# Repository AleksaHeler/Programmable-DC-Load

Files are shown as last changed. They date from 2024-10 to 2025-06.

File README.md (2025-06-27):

# Programmable DC Load

Flexible programmable DC constant current/power load using Arduin Nano and a custom PCB.

Following some ideas from [this YouTube playlist](https://www.youtube.com/playlist?list=PLUMG8JNssPPzbr4LydbTcBrhoPlemu5Dt) from [Scullcom Hobby Electronics](https://www.youtube.com/@scullcomhobbyelectronics1702).

## PCB design and schematic

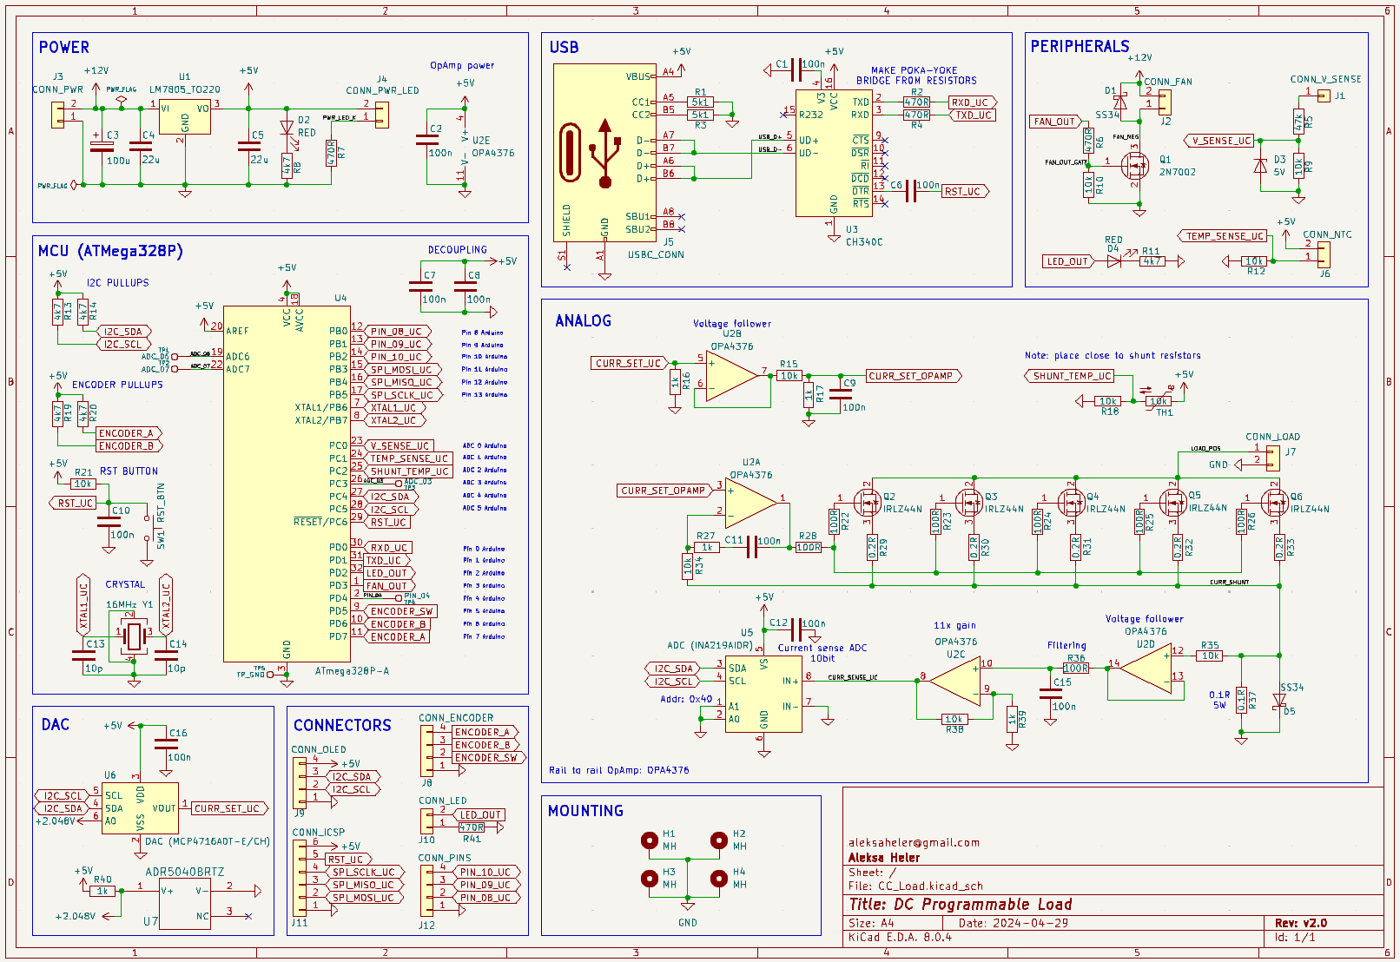
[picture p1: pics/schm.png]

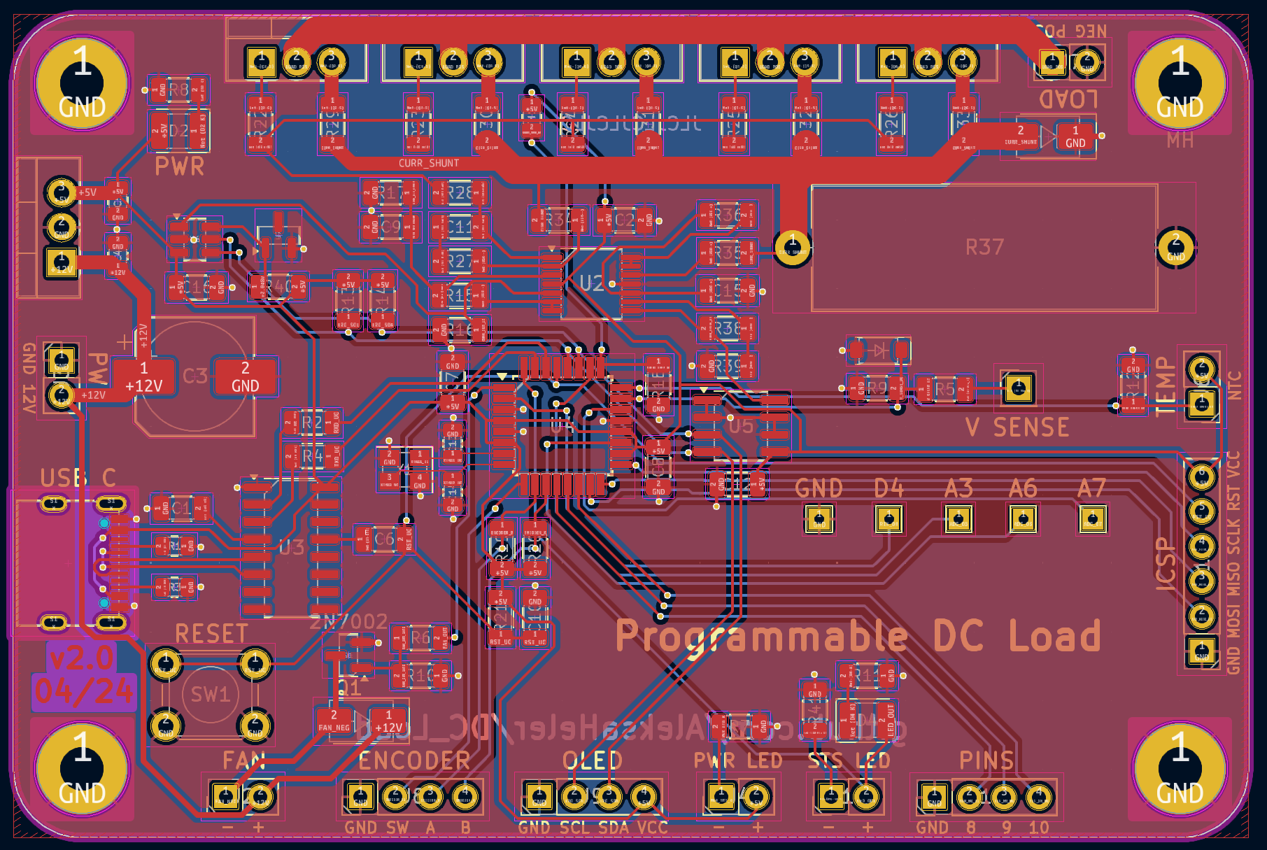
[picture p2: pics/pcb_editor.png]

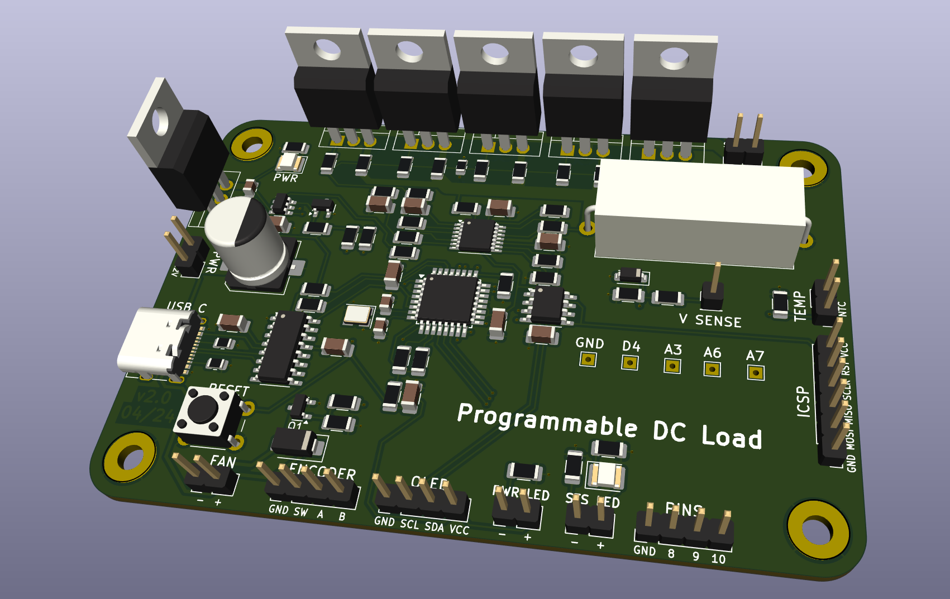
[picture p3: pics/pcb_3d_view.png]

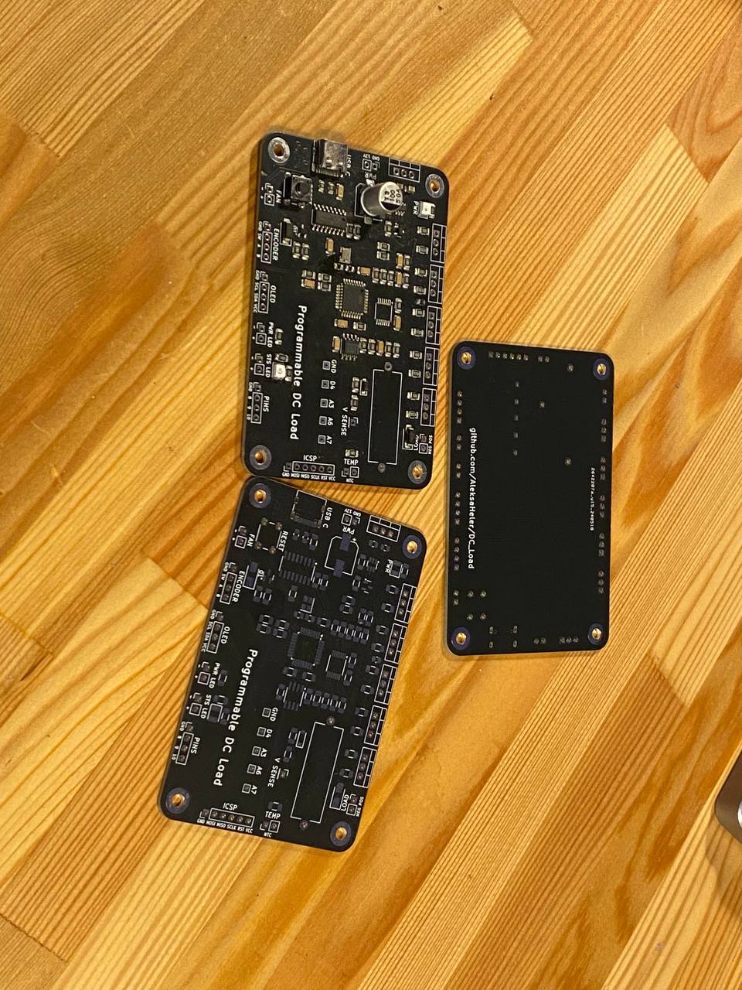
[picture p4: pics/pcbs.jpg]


## Finished device in enclosure

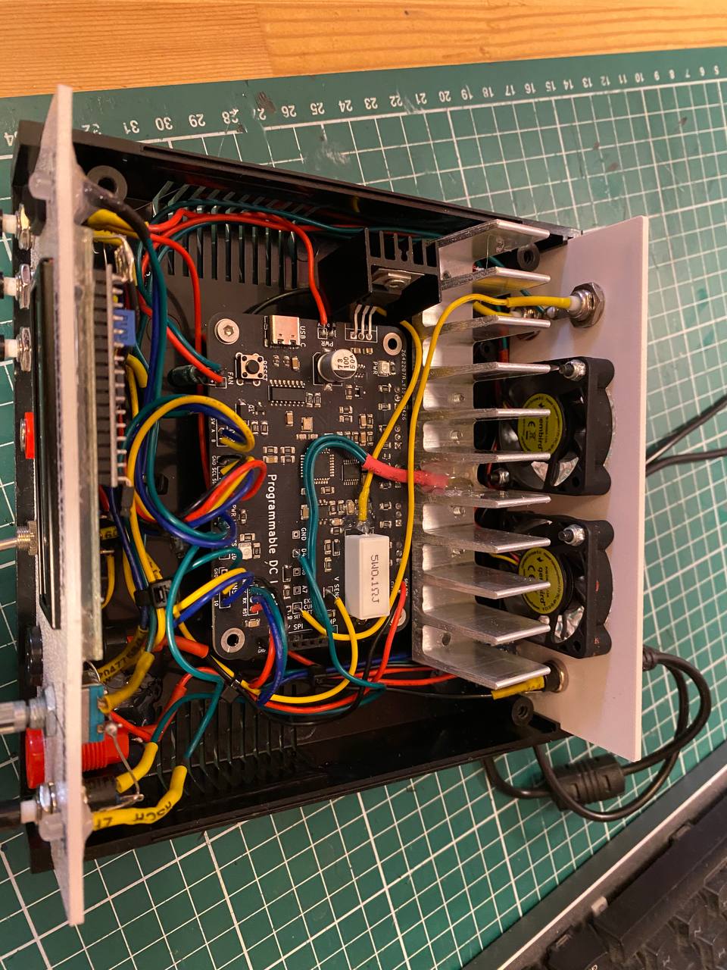
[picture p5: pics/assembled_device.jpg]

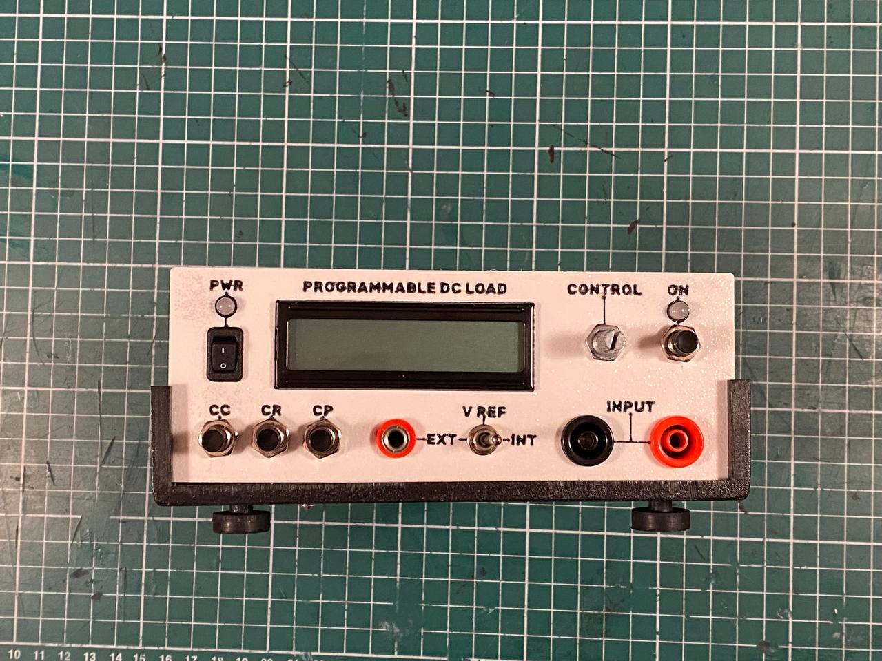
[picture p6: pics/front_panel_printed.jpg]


## Programming the ATmega328P

### Setting the fuses

If you just want the same ones as used in a standard Arduino, you can find them in the ```boards.txt``` file:
```
uno.bootloader.low_fuses=0xff
uno.bootloader.high_fuses=0xde
uno.bootloader.extended_fuses=0x05
```

We will be using another Arduino as ISP, so we should first program it with given example code, then we can use avrdude option 'avrisp', and use the port number of that device. We can read the fuses, and check if conncections are ok with:
``` 
.\utils\avrdude-v8.0\avrdude.exe -c avrisp -p m328p -P com23 -b 19200 -U lfuse:r:-:i -U hfuse:r:-:i -U efuse:r:-:i -v
``` 

So for these default settings we would use the following command:
``` 
.\utils\avrdude-v8.0\avrdude.exe -c avrisp -p m328p -P com23 -b 19200 -U lfuse:w:0xFF:m -U hfuse:w:0xDE:m -U efuse:w:0x05:m -v
```
Where:
```
  -c <programmer>                          Specify programmer type.
  -p <partno>                              Required. Specify AVR device.
  -P <port>                                Specify connection port.
  -b <baudrate>                            Override RS-232 baud rate.
  -U <memtype>:r|w|v:<filename>[:format]   Memory operation specification.
  -v                                       Verbose output. -v -v for more.
```
More options info can be found [here](https://www.nongnu.org/avrdude/user-manual/avrdude_3.html).

### Burning the bootloader

To burn the bootloader, we will also be using Arduino as ISP, and in Arduino software just select burn bootloader after we select the board as Arduino Uno.

### Flashing the program

???

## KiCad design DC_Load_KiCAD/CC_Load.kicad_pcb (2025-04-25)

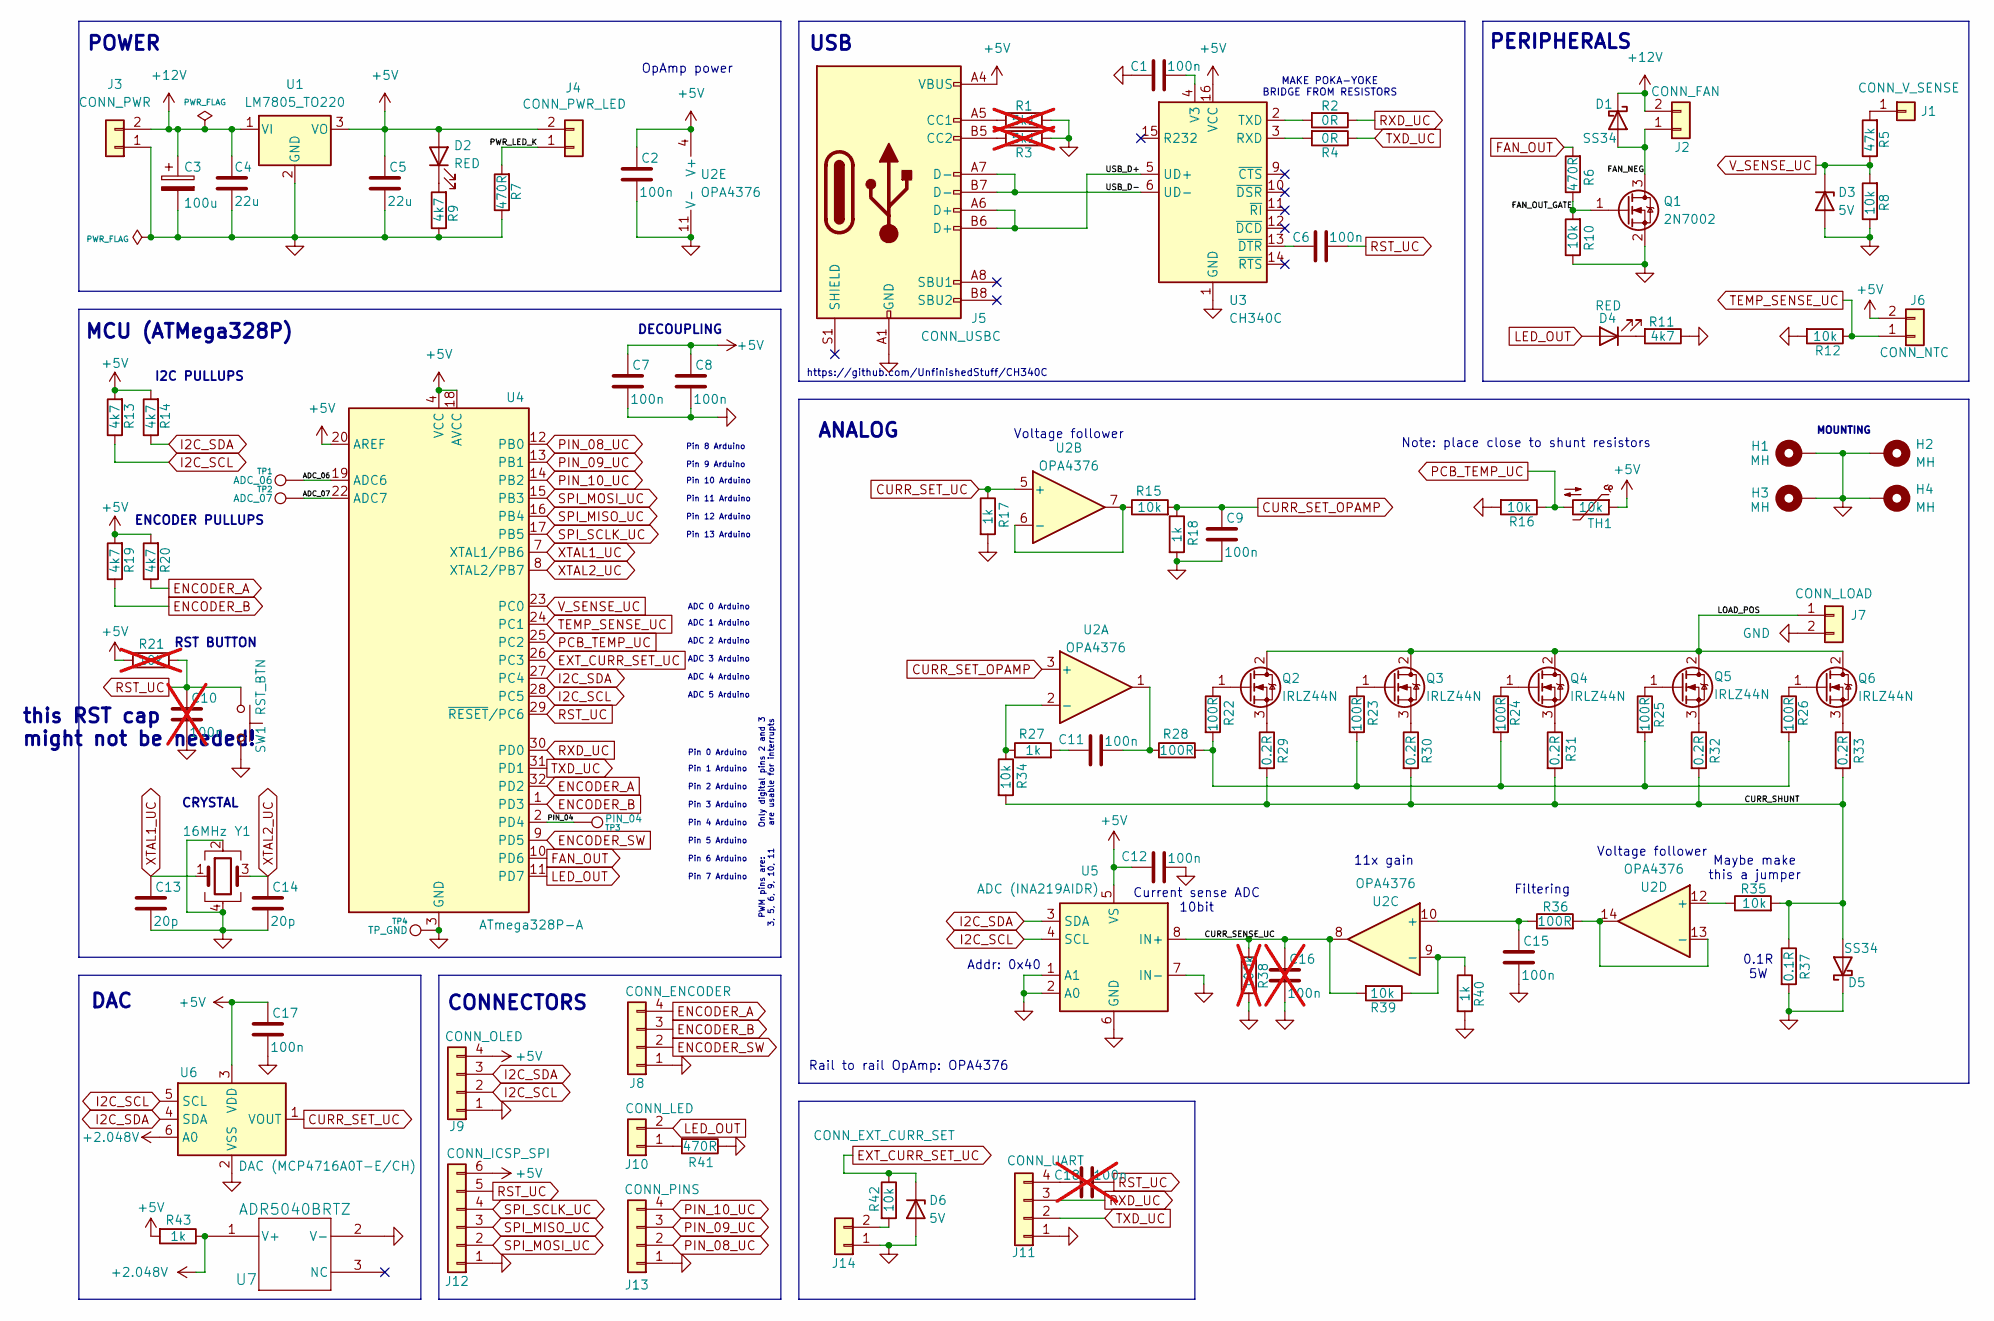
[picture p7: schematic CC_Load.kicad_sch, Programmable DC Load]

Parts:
C1, C2, C6, C7, C8, C9, C11, C12, C15, C17: 100n; C_1206_3216Metric
C3: 100u; CP_Elec_8x10.5
C4, C5: 22u; C_0805_2012Metric
C10, C16, C18: 100n; C_1206_3216Metric; not fitted
C13, C14: 20p; C_0805_2012Metric
D1, D5: SS34; D_SMA
D2, D4: RED; LED_1210_3225Metric
D3, D6: 5V; D_SOD-123
H1, H2, H3, H4: MH; MountingHole_3.2mm_M3_Pad
J1: CONN_V_SENSE; PinHeader_1x01_P2.54mm_Vertical
J2: CONN_FAN; PinHeader_1x02_P2.54mm_Vertical
J3: CONN_PWR; PinHeader_1x02_P2.54mm_Vertical
J4: CONN_PWR_LED; PinHeader_1x02_P2.54mm_Vertical
J5: CONN_USBC; USB_C_Receptacle_G-Switch_GT-USB-7010ASV
J6: CONN_NTC; PinHeader_1x02_P2.54mm_Vertical
J7: CONN_LOAD; PinHeader_1x02_P2.54mm_Vertical
J8: CONN_ENCODER; PinHeader_1x04_P2.54mm_Vertical
J9: CONN_OLED; PinHeader_1x04_P2.54mm_Vertical
J10: CONN_LED; PinHeader_1x02_P2.54mm_Vertical
J11: CONN_UART; PinHeader_1x04_P2.54mm_Vertical
J12: CONN_ICSP_SPI; PinHeader_1x06_P2.54mm_Vertical
J13: CONN_PINS; PinHeader_1x04_P2.54mm_Vertical
J14: CONN_EXT_CURR_SET; PinHeader_1x02_P2.54mm_Vertical
Q1: 2N7002; SOT-23
Q2, Q3, Q4, Q5, Q6: IRLZ44N; TO-220-3_Vertical
R1, R3: 5k1; R_0805_2012Metric; not fitted
R2, R4: 0R; R_1206_3216Metric
R5: 47k; R_1206_3216Metric
R6, R7, R41: 470R; R_1206_3216Metric
R8, R10, R12, R15, R16, R34, R35, R39, R42: 10k; R_1206_3216Metric
R9, R11, R13, R14, R19, R20: 4k7; R_1206_3216Metric
R17, R18, R27, R40, R43: 1k; R_1206_3216Metric
R21: 10k; R_1206_3216Metric; not fitted
R22, R23, R24, R25, R26, R28, R36: 100R; R_1206_3216Metric
R29, R30, R31, R32, R33: 0.2R; R_1206_3216Metric
R37: 0.1R; R_Axial_Power_L25.0mm_W9.0mm_P27.94mm
R38: 100k; R_1206_3216Metric; not fitted
SW1: RST_BTN; SW_PUSH_6mm
TH1: 10k; R_0805_2012Metric
TP1: ADC_06; TestPoint_THTPad_1.5x1.5mm_Drill0.7mm
TP2: ADC_07; TestPoint_THTPad_1.5x1.5mm_Drill0.7mm
TP3: PIN_04; TestPoint_THTPad_1.5x1.5mm_Drill0.7mm
TP4: TP_GND; TestPoint_THTPad_1.5x1.5mm_Drill0.7mm
U1: LM7805_TO220; TO-220-3_Vertical
U2: OPA4376; TSSOP-14_4.4x5mm_P0.65mm
U3: CH340C; SOIC-16_3.9x9.9mm_P1.27mm
U4: ATmega328P-A; TQFP-32_7x7mm_P0.8mm
U5: ADC (INA219AIDR); SOIC-8_3.9x4.9mm_P1.27mm
U6: DAC (MCP4716A0T-E/CH); SOT-23-6
U7: ADR5040BRTZ; SOT-23
Y1: 16MHz; Crystal_SMD_3225-4Pin_3.2x2.5mm

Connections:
+2.048V: R43.1, U6.6 (A0), U7.1 (V+)
+5V: C2.1, C5.1, C7.1, C8.1, C12.1, C17.1, D2.2 (A), J4.2, J5.A4 (VBUS), J5.A9 (VBUS), J5.B4 (VBUS), J5.B9 (VBUS), J6.2, J9.4, J12.6, R13.2, R14.2, R19.2, R20.2, R21.2, R43.2, TH1.1, U1.3 (VO), U2.4 (V+), U3.16 (VCC), U4.4 (VCC), U4.6 (VCC), U4.18 (AVCC), U4.20 (AREF), U5.5 (VS), U6.3 (VDD)
+12V: C3.1, C4.1, D1.1 (K), J2.2, J3.2, U1.1 (VI)
/ADC_06: TP1.1, U4.19 (ADC6)
/ADC_07: TP2.1, U4.22 (ADC7)
/CURR_SENSE_UC: C16.1, R38.1, R39.2, U2.8, U5.8 (IN+)
/CURR_SHUNT: D5.2 (A), R29.2, R30.2, R31.2, R32.2, R33.2, R34.2, R35.2, R37.1
/FAN_NEG: D1.2 (A), J2.1, Q1.3 (D)
/FAN_OUT_GATE: Q1.1 (G), R6.1, R10.2
/LOAD_POS: J7.1, Q2.2 (D), Q3.2 (D), Q4.2 (D), Q5.2 (D), Q6.2 (D)
/PIN_04: TP3.1, U4.2 (PD4)
/PWR_LED_K: J4.1, R7.2
/USB_D+: J5.A6 (D+), J5.B6 (D+), U3.5 (UD+)
/USB_D-: J5.A7 (D-), J5.B7 (D-), U3.6 (UD-)
CURR_SET_OPAMP: C9.1, R15.2, R18.1, U2.3 (+)
CURR_SET_UC: R17.1, U2.5 (+), U6.1 (VOUT)
ENCODER_A: J8.4, R20.1, U4.32 (PD2)
ENCODER_B: J8.3, R19.1, U4.1 (PD3)
ENCODER_SW: J8.2, U4.9 (PD5)
EXT_CURR_SET_UC: D6.1 (K), R42.1, U4.26 (PC3)
FAN_OUT: R6.2, U4.10 (PD6)
GND: C1.1, C2.2, C3.2, C4.2, C5.2, C7.2, C8.2, C9.2, C10.2, C12.2, C13.2, C14.2, C15.2, C16.2, C17.2, D3.2 (A), D5.1 (K), D6.2 (A), H1.1, H2.1, H3.1, H4.1, J3.1, J5.A1 (GND), J5.A12 (GND), J5.B1 (GND), J5.B12 (GND), J7.2, J8.1, J9.1, J11.1, J12.1, J13.1, J14.1, Q1.2 (S), R1.1, R3.1, R7.1, R8.1, R9.1, R10.1, R11.1, R12.2, R16.2, R17.2, R18.2, R37.2, R38.2, R40.2, R41.1, SW1.2, TP4.1, U1.2 (GND), U2.11 (V-), U3.1 (GND), U4.3 (GND), U4.5 (GND), U4.21 (GND), U5.1 (A1), U5.2 (A0), U5.6 (GND), U5.7 (IN-), U6.2 (VSS), U7.2 (V-), Y1.2, Y1.4
I2C_SCL: J9.2, R13.1, U4.28 (PC5), U5.4 (SCL), U6.5 (SCL)
I2C_SDA: J9.3, R14.1, U4.27 (PC4), U5.3 (SDA), U6.4 (SDA)
LED_OUT: D4.2 (A), J10.2, U4.11 (PD7)
unnamed: C11.1, R27.2
unnamed: C11.2, R28.1, U2.1
unnamed: D2.1 (K), R9.2
unnamed: D4.1 (K), R11.2
unnamed: J1.1, R5.2
unnamed: J5.A5 (CC1), R1.2
unnamed: J5.B5 (CC2), R3.2
unnamed: J10.1, R41.2
unnamed: C18.1, J11.4
unnamed: J14.2, R42.2
unnamed: Q2.1 (G), R22.1
unnamed: Q2.3 (S), R29.1
unnamed: Q3.1 (G), R23.1
unnamed: Q3.3 (S), R30.1
unnamed: Q4.1 (G), R24.1
unnamed: Q4.3 (S), R31.1
unnamed: Q5.1 (G), R25.1
unnamed: Q5.3 (S), R32.1
unnamed: Q6.1 (G), R26.1
unnamed: Q6.3 (S), R33.1
unnamed: R22.2, R23.2, R24.2, R25.2, R26.2, R28.2
unnamed: R27.1, R34.1, U2.2 (-)
unnamed: R15.1, U2.6 (-), U2.7
unnamed: C15.1, R36.1, U2.10 (+)
unnamed: R39.1, R40.1, U2.9 (-)
unnamed: R35.1, U2.12 (+)
unnamed: R36.2, U2.13 (-), U2.14
unnamed: R4.2, U3.3 (RXD)
unnamed: R2.2, U3.2 (TXD)
unnamed: C1.2, U3.4 (V3)
unnamed: C6.1, U3.13 (~DTR)
PCB_TEMP_UC: R16.1, TH1.2, U4.25 (PC2)
PIN_08_UC: J13.2, U4.12 (PB0)
PIN_09_UC: J13.3, U4.13 (PB1)
PIN_10_UC: J13.4, U4.14 (PB2)
RST_UC: C6.2, C10.1, C18.2, J12.5, R21.1, SW1.1, U4.29 (~RESET/PC6)
RXD_UC: J11.3, R2.1, U4.30 (PD0)
SPI_MISO_UC: J12.3, U4.16 (PB4)
SPI_MOSI_UC: J12.2, U4.15 (PB3)
SPI_SCLK_UC: J12.4, U4.17 (PB5)
TEMP_SENSE_UC: J6.1, R12.1, U4.24 (PC1)
TXD_UC: J11.2, R4.1, U4.31 (PD1)
V_SENSE_UC: D3.1 (K), R5.1, R8.2, U4.23 (PC0)
XTAL1_UC: C13.1, U4.7 (XTAL1/PB6), Y1.1
XTAL2_UC: C14.1, U4.8 (XTAL2/PB7), Y1.3

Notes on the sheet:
DAC
Pin 12 Arduino
ANALOG
Pin 10 Arduino
ENCODER PULLUPS
POWER
Rail to rail OpAmp: OPA4376
Pin 0 Arduino
OpAmp power
Pin 8 Arduino
DECOUPLING
I2C PULLUPS
Only digital pins 2 and 3 are usable for interrupts
Pin 2 Arduino
Voltage follower
https://github.com/UnfinishedStuff/CH340C
Pin 13 Arduino
Current sense ADC 10bit
CRYSTAL
PWM pins are: 3, 5, 6, 9, 10, 11
Pin 7 Arduino
Pin 4 Arduino
ADC 1 Arduino
MAKE POKA-YOKE BRIDGE FROM RESISTORS
USB
ADC 4 Arduino
ADC 0 Arduino
this RST cap might not be needed!
CONNECTORS
PERIPHERALS
ADC 3 Arduino
Pin 9 Arduino
Addr: 0x40
ADC 5 Arduino
Filtering
ADC 2 Arduino
RST BUTTON
MOUNTING
0.1R 5W
Pin 11 Arduino

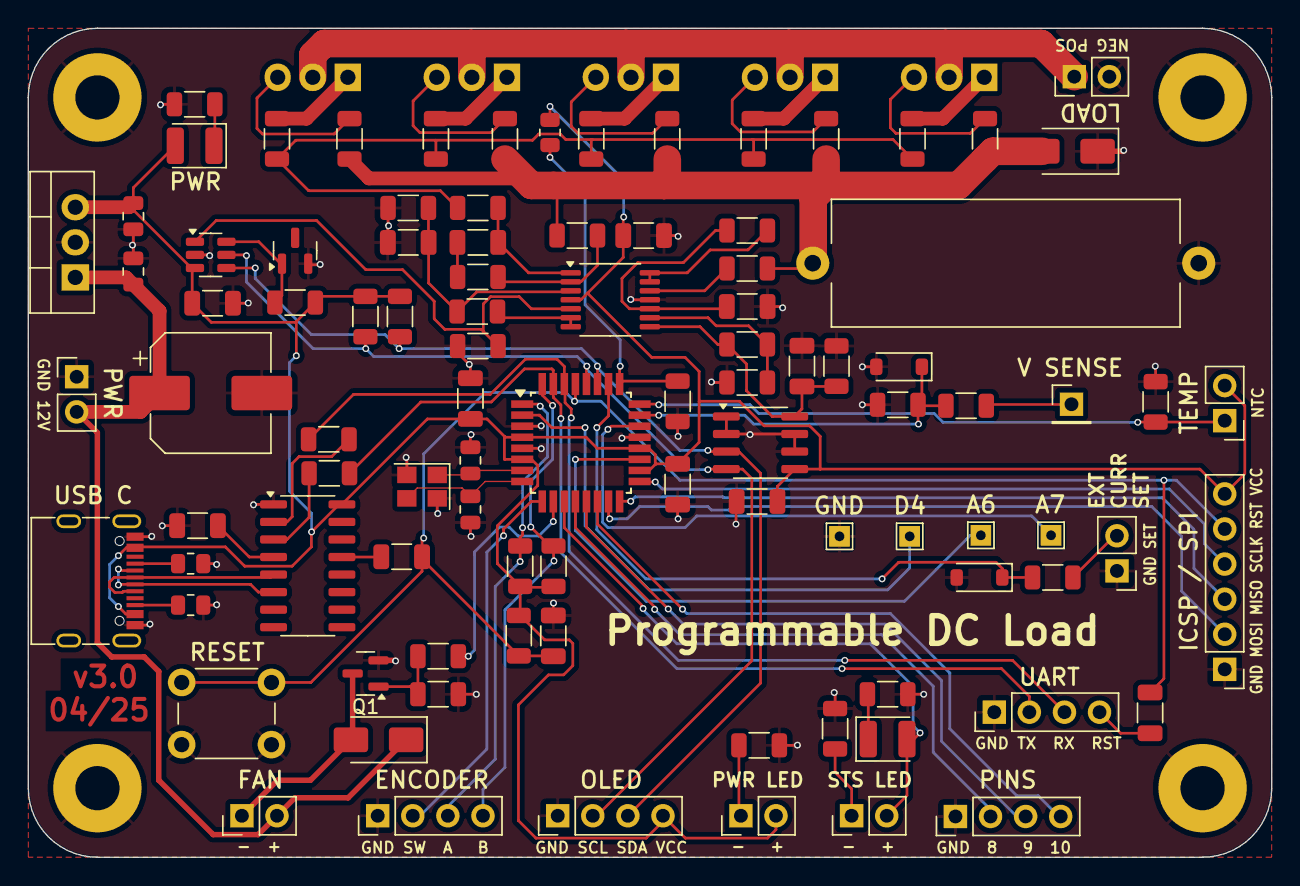
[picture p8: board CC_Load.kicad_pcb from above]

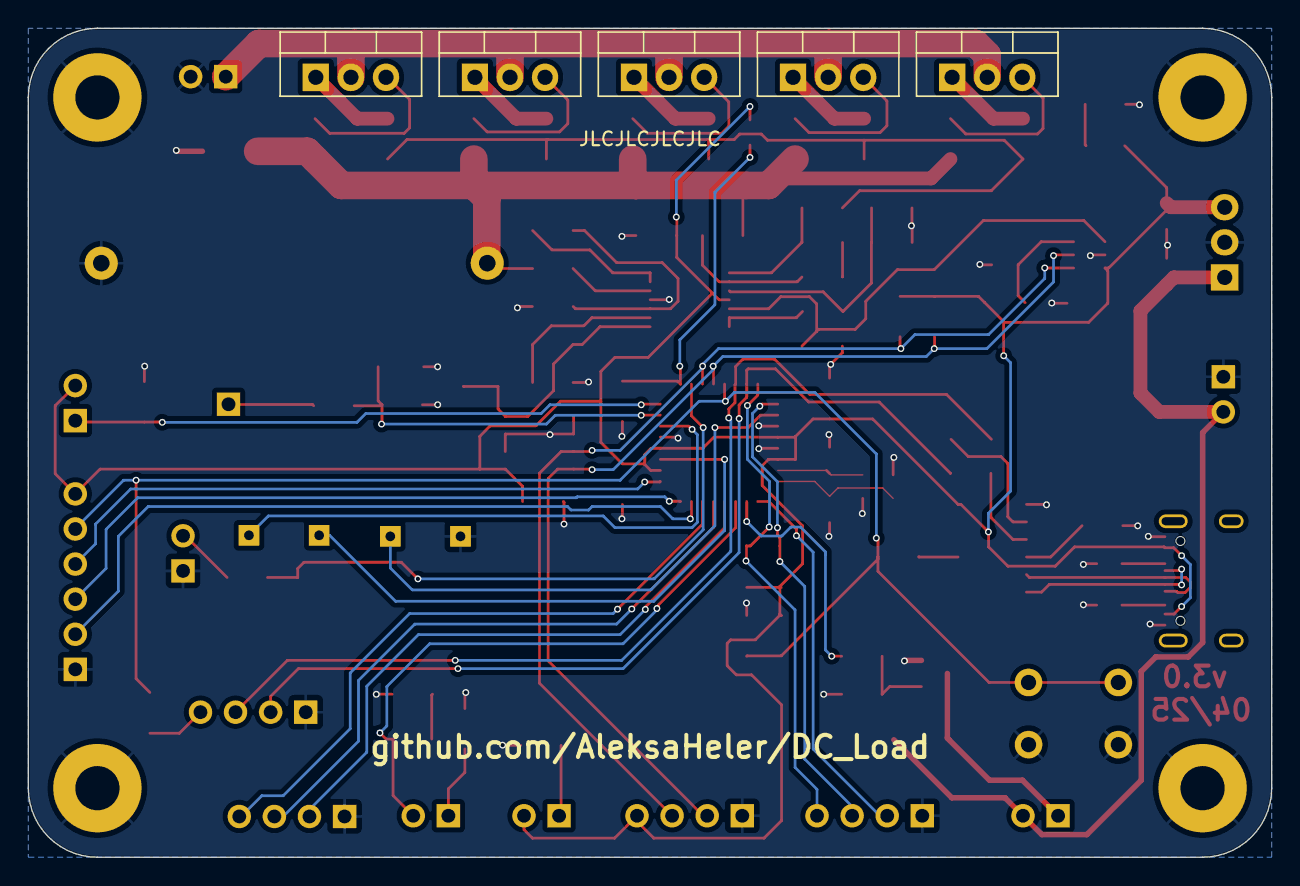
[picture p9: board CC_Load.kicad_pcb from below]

Board: 2 copper layers, 90.0 x 60.0 mm, 105 parts (5 on the bottom side), 70 nets.

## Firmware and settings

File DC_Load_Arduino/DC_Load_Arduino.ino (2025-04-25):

/*
 * This program is intended to be used to control a programmable electronic DC load.
 * Interfacing is possible with a rotary encoder and a 16x2 LCD display, to set mode (CC, CR, CP)
 * and to configure it and track the state of the whole device.
 *
 * TODO: develop and implement calibration feature (without reprogramming the device, EEPROM)
 * TODO: adapt for variant with other external ADCs and DACs
 * TODO: update LCD screen to have more info and cycle between some things
 * TODO: add timer so that we have precise 10ms cycles (and measure execution time just for reference)
 * TODO: add a mode for batteries, to set the cut-off voltage when to stop current
 * 
 * 
 * From INA219 datasheet, chapter 9.2:
 *  Current_LSB = Max expected current / 2^15
 *  Cal = trunc ( 0.04096 / Current_LSB * Rshunt ) // trunc = floor, round the value down
 * So for our case, max current is 5A, and Rshunt is 0.1 Ohm
 *  Current_LSB = 5A / 32768 = 0.000152587890625 A = 0.1526 mA
 *  Cal = trunc ( 0.04096 / 0.000152587890625 * 0.1 ) = trunc(2672.0) = 2672
 * This value is then programmed into the Calibration register
 * 
 */

/* Include our helper files */
#include "defines.h"   /* Global defines */
#include "sensing.h"   /* Handle sensing of current and voltage */
#include "ntc.h"       /* Handle NTC temperature sensors */
#include "encoder.h"   /* Handle rotary encoder */
#include "dac.h"       /* Handle DAC output */
#include "leds.h"      /* Handle status LEDs */
#include "fan.h"       /* Handle fan */
#include "oled.h"      /* Handle OLED display */
#include "logger.h"    /* Handle logging */


/* First setup all used helper modules */
void setup() 
{
  Serial.begin(9600); /* Start serial communication for debugging */
  Serial.println("Starting DC Load program...");

  sensing_setup(); /* Sensing of current and voltage */
  ntc_setup();     /* NTC temperature input */
  encoder_setup(); /* Encoder input */
  dac_setup();     /* DAC output for current */
  leds_setup();    /* LED status output */
  fan_setup();     /* Fan driver output */
  oled_setup();    /* OLED display output */
  logger_setup();  /* Logger output */

  leds_set_led(0, led_blink_slow); /* Set LED to blink slowly */
  Serial.println("Setup complete!");
}

/* During loop, just call helper function to handle all the functionality every 10ms */
void loop() 
{
  sensing_handle(); /* Read voltage and current */
  ntc_handle();     /* Read NTC temperatures */
  encoder_handle(); /* Read encoder input */
  dac_handle();     /* Handle DAC output */
  leds_handle();    /* Handle LED states and blinking */
  fan_handle();     /* Handle fan driver */
  oled_handle();    /* Handle OLED display */
  logger_handle();  /* Handle logging */

  // dac_set_output(0.2); // Set DAC to x volts
  // fan_set_pwm(90); // Set fan to x%
  // ntc_temperatures[0]  // PCB temperature
  // ntc_temperatures[1]  // External temperature

  fan_set_pwm(encoderPosition);
  
  delay(1);
}

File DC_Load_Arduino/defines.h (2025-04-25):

/*
* Here we mostly define pins and global configurations, for module-specific
* configurations see the module .h files
*/
#ifndef DEFINES_H
#define DEFINES_H

/****************************************************************************************/
/* Logic defines                                                                        */
/****************************************************************************************/

/* Define maximum values */
#define LOAD_MAX_VOLTAGE (28.5f)   /* V */
#define LOAD_MAX_CURRENT (2.0f)    /* A */
#define LOAD_MAX_POWER 20          /* W */

/****************************************************************************************/
/* Hardware/pin defines                                                                 */
/****************************************************************************************/

/* I2C: ADC/DAC, OLED display  */
#define DAC_MCP4716_I2C_ADDRESS 0x60  /* Set current via precise DAC */
#define ADC_INA219_I2C_ADDRESS 0x40   /* Measure current via shunt resistor (A0 and A1 pin of IC are connected to GND)*/
#define OLED_I2C_ADDRESS 0x3C         /* Typical 64x128 OLED display */
#define OLED_RESET -1                 /* Reset pin # (or -1 if sharing Arduino reset pin) */

/* Encoder pins */
#define ENCODER_PIN_A 7
#define ENCODER_PIN_B 6
#define ENCODER_SWITCH 5

/* Analog inputs */
#define INPUT_VOLTAGE_PIN A0
#define NTC_NUM 2                    /* How many status NTCs we have */
const int NTC_PINS[NTC_NUM] = {      /* NTC pins */
  A2,  /* NTC_PCB_TEMP_PIN */
  A1   /* NTC_EXT_TEMP_PIN */
};

/* Digital outputs */
#define FAN_PIN 3
#define LED_NUM 1                      /* How many status LEDs we have */
const int LED_PINS[LED_NUM] = { 2 };   /* Status LED pins */

/* Define encoder positive direction: right = 1, left = -1 */
#define ENCODER_DIRECTION (-1)
/* Define encoder step value (0-100%) */
#define ENCODER_STEP (1)

/* Input voltage divider values */
#define INPUT_VOLTAGE_R1 47 /* Resistor from Vin to midpoint (kOhm) */
#define INPUT_VOLTAGE_R2 10 /* Resistor from midpoint to ground (kOhm) */
#define INPUT_VOLTAGE_FACTOR 1.015 /* Voltage is multiplied by this number to offset any resitor deviations */

/* Output DAC scaling factor, used to convert it's output voltage to amps */
#define DAC_OUTPUT_FACTOR 1.13f /* DAC output voltage is multiplied by this number to offset any resitor deviations */
#define DAC_VREF 5.0f /* DAC reference voltage, 5V bus */
#define INPUT_CURRENT_FACTOR 1.034f /* Current is multiplied by this number to offset any resitor deviations */

/****************************************************************************************/
/* Other defines                                                                        */
/****************************************************************************************/


#endif /* DEFINES_H */

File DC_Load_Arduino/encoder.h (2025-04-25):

/**
 * @file encoder.h
 * 
 * @brief This file contains encoder handling functions
 * 
 * Encoder has two pins, A and B for rotation
 * And a push button/switch for press
 * 
 */
#ifndef ENCODER_H
#define ENCODER_H

#include "defines.h"

/* Variables to track encoder state */
int encoderPosition = 0;
bool buttonPressed = false;
int lastEncoded = 0;
int lastButtonState = HIGH;
unsigned long lastDebounceTime = 0;
const unsigned long debounceDelay = 50;

/* Prototypes for all used functions */
void encoder_setup();
void encoder_handle();

/**
 * @brief Setup
 */
void encoder_setup()
{
  pinMode(ENCODER_PIN_A, INPUT);
  pinMode(ENCODER_PIN_B, INPUT);
  pinMode(ENCODER_SWITCH, INPUT_PULLUP);

  // Initialize encoder state
  int MSB = digitalRead(ENCODER_PIN_A); // Most significant bit
  int LSB = digitalRead(ENCODER_PIN_B); // Least significant bit
  lastEncoded = (MSB << 1) | LSB;
}

/**
 * @brief Handle
 */
void encoder_handle()
{  
  // Handle encoder rotation
  int MSB = digitalRead(ENCODER_PIN_A);
  int LSB = digitalRead(ENCODER_PIN_B);
  int encoded = (MSB << 1) | LSB;
  int sum = (lastEncoded << 2) | encoded;

  if (sum == 0b1101 || sum == 0b0100 || sum == 0b0010 || sum == 0b1011) encoderPosition++;
  if (sum == 0b1110 || sum == 0b0111 || sum == 0b0001 || sum == 0b1000) encoderPosition--;

  lastEncoded = encoded;

  // Print position if changed
  static int lastReportedPosition = 0;
  if (encoderPosition != lastReportedPosition) {
    lastReportedPosition = encoderPosition;
  }

  // Handle button press with debounce
  int reading = digitalRead(ENCODER_SWITCH);

  if (reading != lastButtonState) {
    lastDebounceTime = millis();
  }

  if ((millis() - lastDebounceTime) > debounceDelay) {
    if (reading == LOW && !buttonPressed) {
      buttonPressed = true;
      Serial.println("Button Pressed");
    } else if (reading == HIGH) {
      buttonPressed = false;
    }
  }

  lastButtonState = reading;
}

#endif ENCODER_H

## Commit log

2023-10-29 Started making the schematic
    [electronic_dc_load.kicad_pcb, electronic_dc_load.kicad_sch]
2023-11-28 Create a whole new schematic for this project
    [CC_Load.kicad_pcb, CC_Load.kicad_sch, electronic_dc_load.kicad_pcb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]
2023-11-29 Finished first design for my DIY PCB
    [CC_Load.kicad_pcb, CC_Load.kicad_sch]
2023-11-30 Changed PCB design, will order from JLCPCB
    [CC_Load-B_Cu.gbr, CC_Load-B_Mask.gbr, CC_Load-B_Paste.gbr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]
2023-12-08 Add DIY PCB version for initial testing
    [CC_Load.kicad_pcb, CC_Load.kicad_sch]
2023-12-12 Update schematic and code
    [CC_Load-B_Cu.gbr, CC_Load-B_Mask.gbr, CC_Load-B_Paste.gbr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]
2023-12-16 Update both code and kicad
    [CC_Load.kicad_pcb, CC_Load.kicad_sch]
2024-05-02 Update PCB and prepare for ordering
    [CC_Load-B_Courtyard.gbr, CC_Load-B_Cu.gbr, CC_Load-B_Mask.gbr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]
2024-05-17 Final review and order from JLCPCB
    [CC_Load-B_Courtyard.gbr, CC_Load-B_Cu.gbr, CC_Load-B_Mask.gbr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]
2025-04-23 Added comments for future improvements, successfully flashed one device
    [CC_Load.kicad_sch]
2025-04-23 Update initial code with simple drivers
    [CC_Load.kicad_pcb, CC_Load.kicad_sch, NTC_Lookup_Table.ods]
2025-04-25 Update PCB to ver 3.0, in code updatet drivers a bit
    [CC_Load-B_Courtyard.gbr, CC_Load-B_Cu.gbr, CC_Load-B_Mask.gbr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]
